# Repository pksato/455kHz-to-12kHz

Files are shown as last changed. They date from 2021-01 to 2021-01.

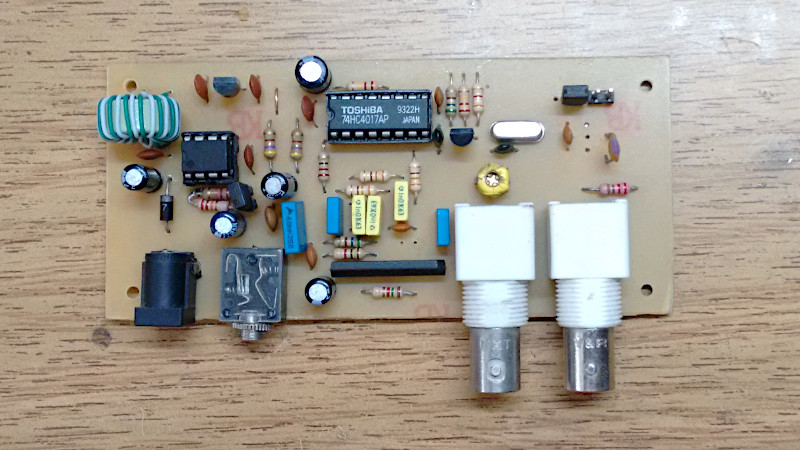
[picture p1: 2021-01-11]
if-455-to-12khz_bnc.jpg

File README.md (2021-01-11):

# IF down converter, 455kHz to 12kHz.
This converter allow a shortwave radio to decode DRM (Digital Radio Mondiale) broadcast using a SDR software.  
  
The circuit use a LA1186N or TA7358AP as mixer, and a analog television chrominance crystal as source to local oscillator.  
The crystal frequency are divide by IC301, and need to selected between 74HC4017 or 74HC4040, depending on choosen crystal frequency.  
To get 12kHz output use 4.433619MHz (PAL) crystal and 74HC4017.  
Using the 74HC4040 and 3.579545MHz (NTSC) or 3.575611MHz (PAL-M) crystal, the output frequency are centered near 8kHz.  
The input impedance of converter are great that 6k.  
Total gain is 12dB.  
  
On the radio, FI signal need to tapped after last IF stage of after 455kHz ceramic filter. Use a 47pF (or lowwer) to decouple the signal.  
  
...

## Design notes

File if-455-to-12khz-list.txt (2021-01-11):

455kHz to 12kHz converter part list.
  
Part	Value         	Description
  C101	10nF          	Ceramic Capacitor
  C102	100pF         	Ceramic Capacitor
  C103	3n3           	Ceramic Capacitor
  C104	100uFx16V       Electrolytic Capacitor
  C105	100nF         	Ceramic Capacitor
  C201	2.2uFx16V       Electrolytic Capacitor
  C202	560pF         	Ceramic Capacitor
  C203	2.2uFx16V       Electrolytic Capacitor
  C204	10uFx16V        Electrolytic Capacitor
  C205	100nF         	Ceramic Capacitor
  C301	27pF          	Ceramic Capacitor
  C302	27pF          	Ceramic Capacitor
  C303	100pF         	Ceramic Capacitor
  C304	100nF         	Ceramic Capacitor
  C305	1nF           	Ceramic Capacitor
  C306	1nF           	Ceramic Capacitor
  C307	1nF           	Ceramic Capacitor
  C308	100pF         	Ceramic Capacitor
  C401	100uFx16V       Electrolytic Capacitor
  C402	100nF         	Ceramic Capacitor
  C403	100nF         	Ceramic Capacitor
  C404	100nF         	Ceramic Capacitor
  C405	10uFx16V        Electrolytic Capacitor
 CV101	40pF          	Ceramic Trimmer
 CX101	3n3           	Only for TA7358AP - Ceramic Capacitor
  D401	1N4007        	Diode
 IC101	LA1186N       	Or TA7358AP - FM RF Front End.
 IC201	LM1458N       	Dual OpAmp
 IC301	DIL16         	74HC4017 or 74HC4040 
                        (according to the chosen crystal, see schematic)
 IC401	78L05         	Voltage regulator
  J101	1503_09       	3.5mm Jack
  J202	1503_09       	3.5mm Jack
  J401	JACK-PLUG0    	Power Jack
  L401/L402	            Common mode choke, bifilar winding on ferrite toroid
  Q301	KSP2222A      	NPN Transistor
  R101	1k5           	Resistor 1/8W
  R102	(560)         	390Ohms for TA7358AP Resistor 1/8W
  R103	1k            	Resistor 1/8W
  R201	10k           	Resistor 1/8W
  R202	4k7           	Resistor 1/8W
  R203	4k7           	Resistor 1/8W
  R301	220k          	Resistor 1/8W
  R302	560           	Resistor 1/8W
  R303	3k9           	Resistor 1/8W
  R304	220k          	Resistor 1/8W
  R305	330           	Resistor 1/8W
  R306	330           	Resistor 1/8W
  R307	330           	Resistor 1/8W
  R401	22            	Resistor 1/8W
  X301	MHz           	PAL 4.433619MHz, PAL-M 3.575611MHz or
                        NTSC 3.579545Mhz Chroma Crystal.

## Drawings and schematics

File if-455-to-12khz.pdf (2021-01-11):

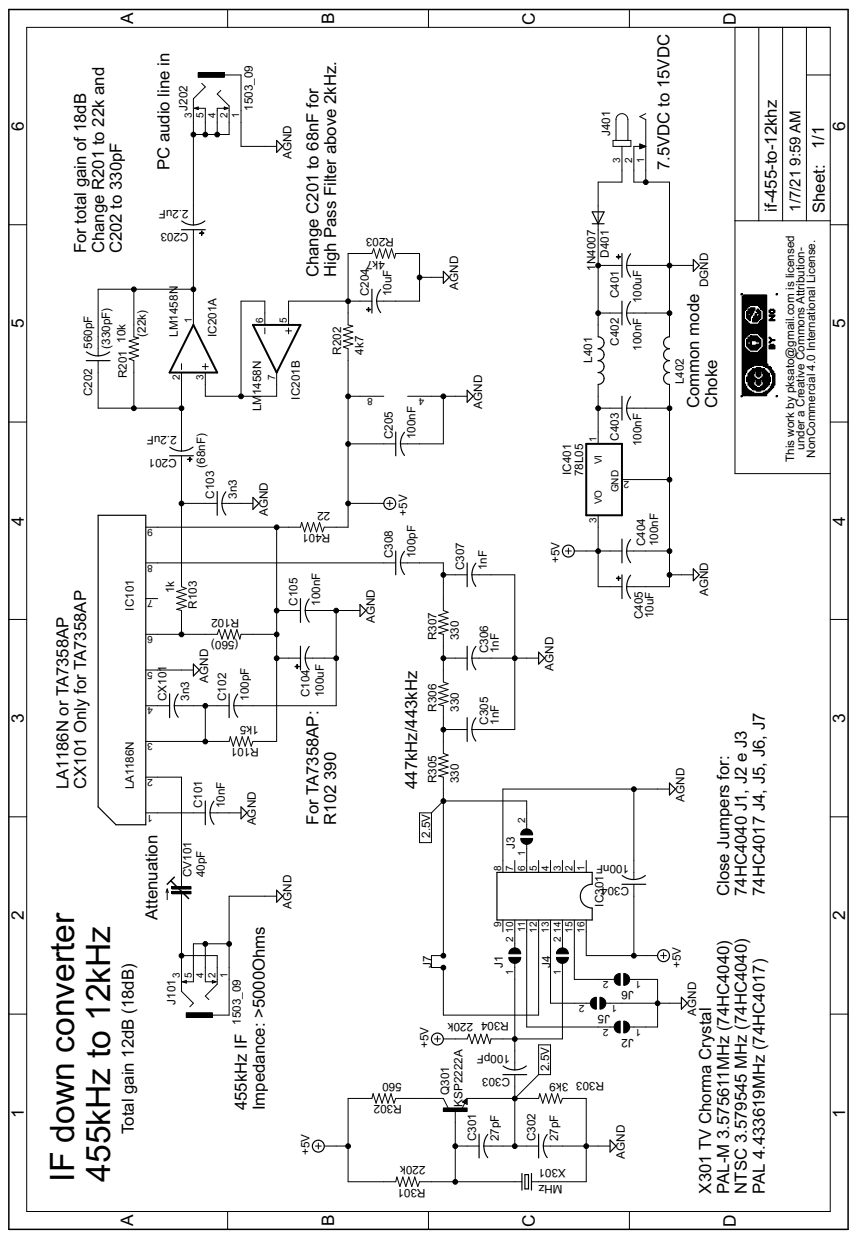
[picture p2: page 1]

PC audio line in

High Pass Filter above 2kHz.

For total gain of 18dB

This work by pksato@gmail.com is licensed under a Creative Commons Attribution-

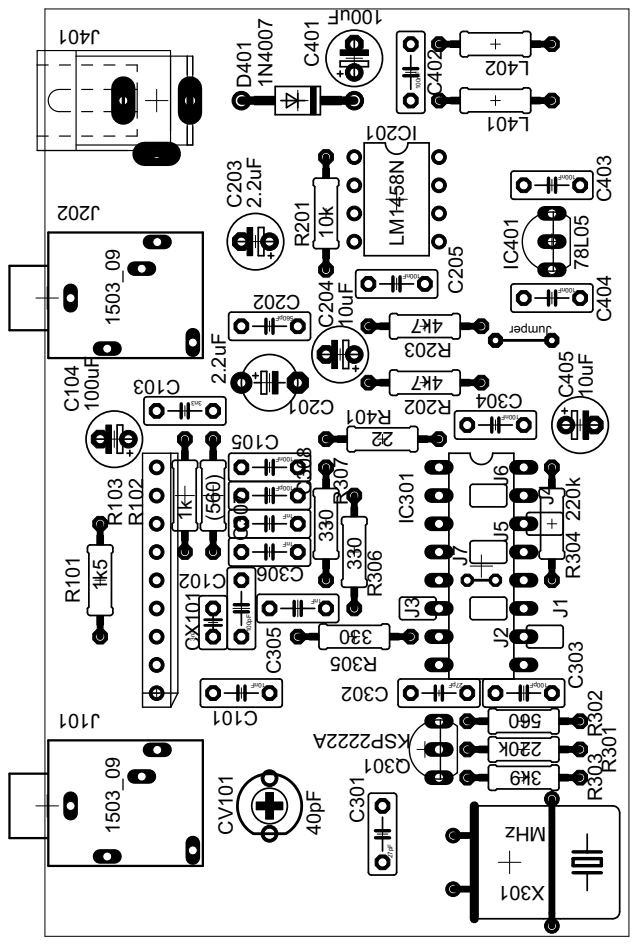
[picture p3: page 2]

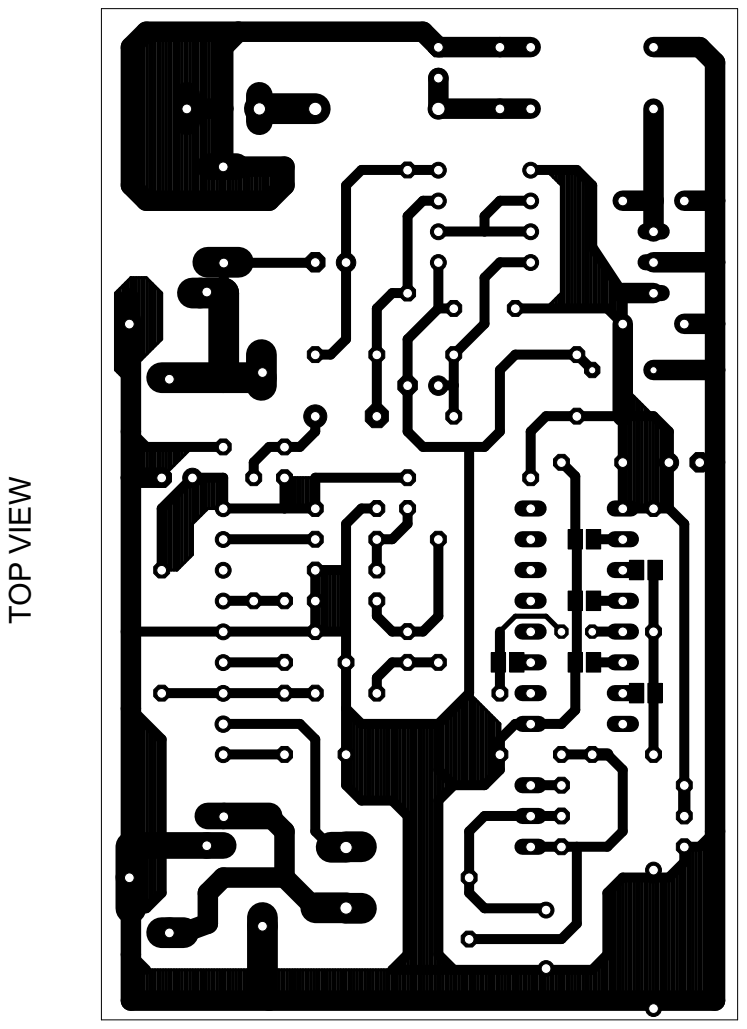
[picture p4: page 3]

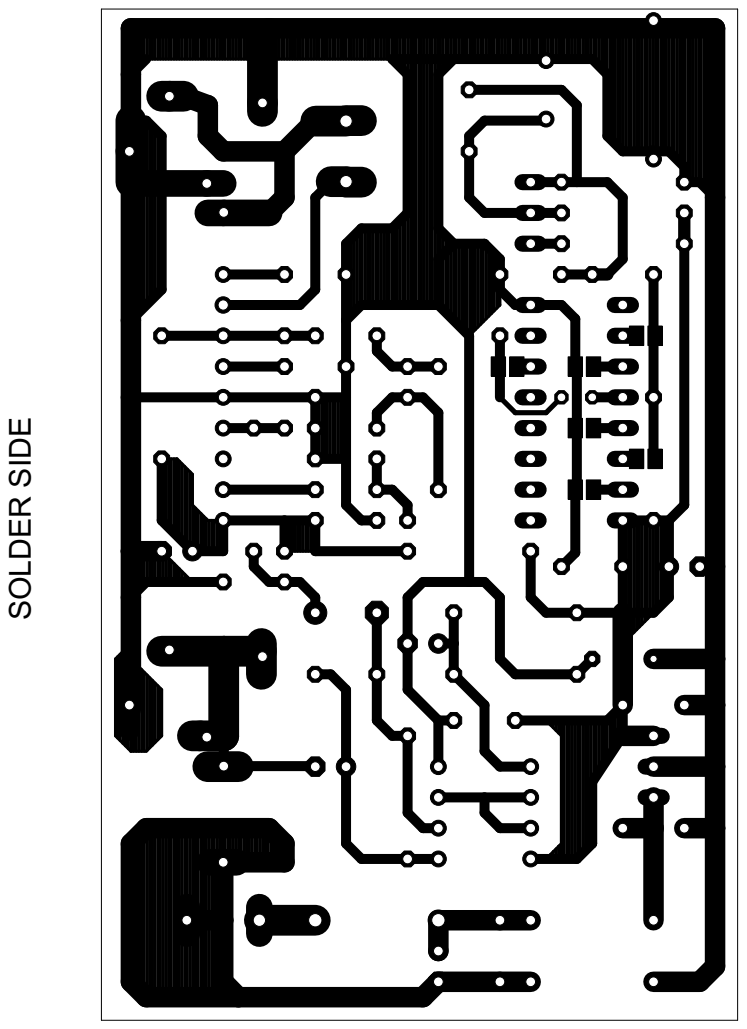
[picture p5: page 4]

455kHz to 12kHz converter part list.

Part | Value | Description
C101 | 10nF | Ceramic Capacitor
C102 | 100pF | Ceramic Capacitor
C103 | 3n3 | Ceramic Capacitor
C104 | 100uFx16V | Electrolytic Capacitor
C105 | 100nF | Ceramic Capacitor
C201 | 2.2uFx16V | Electrolytic Capacitor
C202 | 560pF | Ceramic Capacitor
C203 | 2.2uFx16V | Electrolytic Capacitor
C204 | 10uFx16V | Electrolytic Capacitor
C205 | 100nF | Ceramic Capacitor
C301 | 27pF | Ceramic Capacitor
C302 | 27pF | Ceramic Capacitor
C303 | 100pF | Ceramic Capacitor
C304 | 100nF | Ceramic Capacitor
C305 | 1nF | Ceramic Capacitor
C306 | 1nF | Ceramic Capacitor
C307 | 1nF | Ceramic Capacitor
C308 | 100pF | Ceramic Capacitor
C401 | 100uFx16V | Electrolytic Capacitor
C402 | 100nF | Ceramic Capacitor
C403 | 100nF | Ceramic Capacitor
C404 | 100nF | Ceramic Capacitor
C405 | 10uFx16V | Electrolytic Capacitor
CV101 | 40pF | Ceramic Trimmer
CX101 | 3n3 | Only for TA7358AP - Ceramic Capacitor
D401 | 1N4007 | Diode
IC101 | LA1186N | Or TA7358AP - FM RF Front End.
IC201 | LM1458N | Dual OpAmp
IC301 | DIL16 | 74HC4017 or 74HC4040
| | (according to the chosen crystal, see schematic)
IC401 | 78L05 | Voltage regulator
J101 | 1503_09 | 3.5mm Jack
J202 | 1503_09 | 3.5mm Jack
J401 | JACK-PLUG0 | Power Jack
L401/L402 | Common mode choke, bifilar winding on ferrite toroid
Q301 | KSP2222A | NPN Transistor
R101 | 1k5 | Resistor 1/8W
R102 | (560) | 390Ohms for TA7358AP Resistor 1/8W
R103 | 1k | Resistor 1/8W
R201 | 10k | Resistor 1/8W
R202 | 4k7 | Resistor 1/8W
R203 | 4k7 | Resistor 1/8W
R301 | 220k | Resistor 1/8W
R302 | 560 | Resistor 1/8W
R303 | 3k9 | Resistor 1/8W
R304 | 220k | Resistor 1/8W
R305 | 330 | Resistor 1/8W
R306 | 330 | Resistor 1/8W
R307 | 330 | Resistor 1/8W
R401 | 22 | Resistor 1/8W
X301 | MHz | PAL 4.433619MHz, PAL-M 3.575611MHz or
| | NTSC 3.579545Mhz Chroma Crystal.

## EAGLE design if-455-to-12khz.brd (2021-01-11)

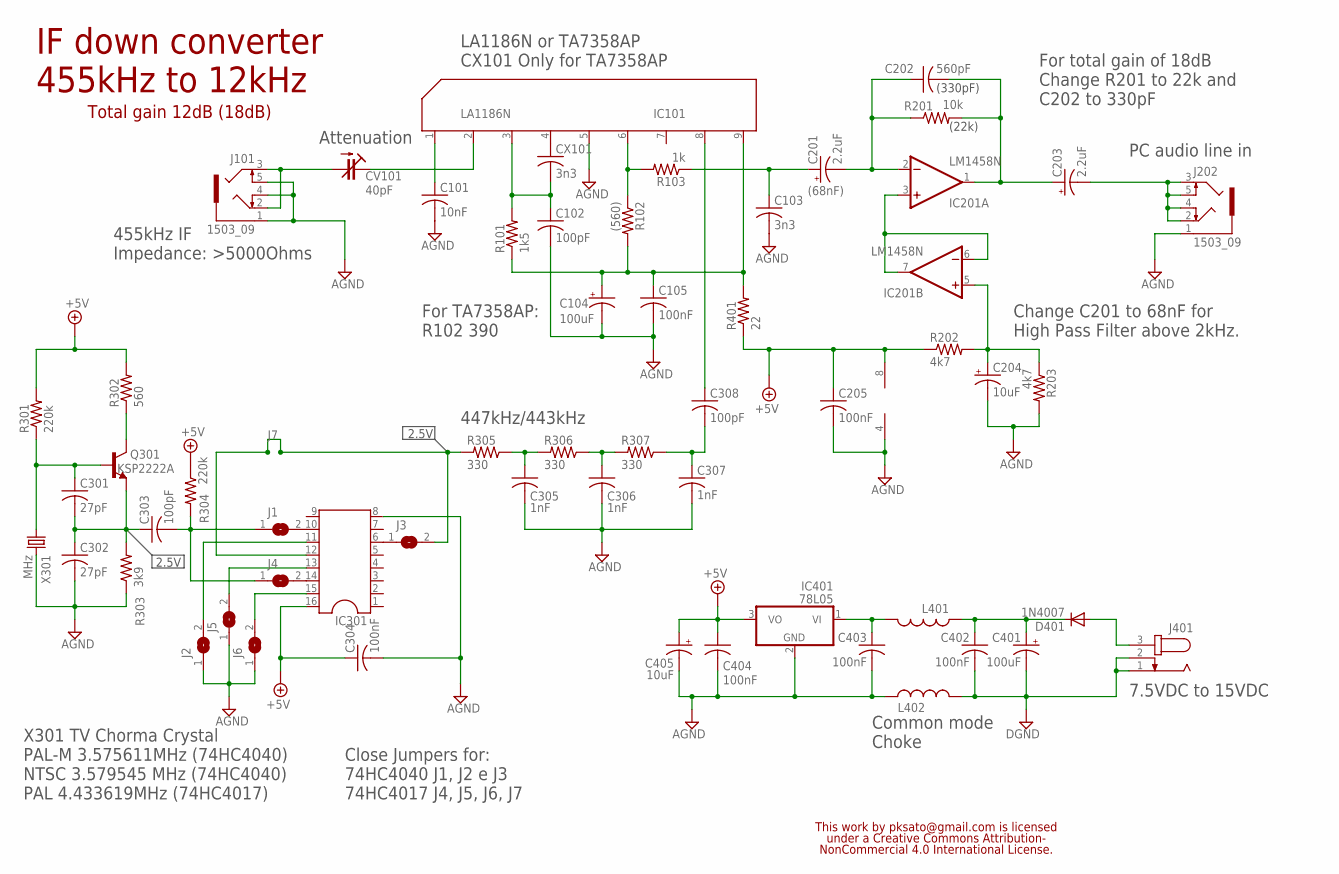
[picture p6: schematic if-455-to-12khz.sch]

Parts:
C101: 10nF; C050-025X075
C102, C303, C308: 100pF; C050-025X075
C103: 3n3; C050-025X075
C104, C401: 100uF; E2,5-5
C105, C205, C304, C402, C403, C404: 100nF; C050-025X075
C201: 2.2uF; E5-5
C202: 560pF; C050-025X075
C203: 2.2uF; E2,5-5
C204, C405: 10uF; E2,5-5
C301, C302: 27pF; C050-025X075
C305, C306, C307: 1nF; C050-025X075
CV101: 40pF; CTRIMTZ03
CX101: 3n3; C025-025X050
D401: 1N4007; DO41-10
IC101: LA1186N; SIP09
IC201: LM1458N; DIL08
IC301: DIL16
IC401: 78L05; TO92-
J1, J2, J3, J4, J5, J6: SJ
J101, J202: 1503_09
J401: JACK-PLUG0; SPC4077
L401, L402: L-US0207/10; 0207/10
Q301: KSP2222A; TO92-EBC
R101: 1k5; 0207/10
R102: (560); 0207/10
R103: 1k; 0207/10
R201: 10k; 0207/10
R202, R203: 4k7; 0207/10
R301, R304: 220k; 0207/10
R302: 560; 0207/10
R303: 3k9; 0207/10
R305, R306, R307: 330; 0207/10
R401: 22; 0207/10
X301: MHz; HC49U-LM

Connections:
+5V: C205.1, C304.1, C404.1, C405.+, IC201.8 (V+), IC301.16, IC401.3 (VO), R202.1, R301.2, R302.2, R304.1, R401.1
AGND: C101.2, C102.2, C103.2, C104.-, C105.2, C204.-, C205.2, C302.2, C304.2, C305.2, C306.2, C307.2, C403.2, C404.2, C405.-, IC101.5, IC201.4 (V-), IC301.8, IC401.2 (GND), J2.1, J5.1, J6.1, J101.1, J101.4, J101.5, J202.1, L402.2, R203.2, R303.1, X301.2
DGND: C401.-, C402.2, J401.1, J401.2, L402.1
unnamed: C301.1, Q301.B, R301.1, X301.1
unnamed: C301.2, C302.1, C303.1, Q301.E, R303.2
unnamed: CV101.2 (A), J101.2, J101.3
unnamed: C101.1, IC101.1
unnamed: IC301.12, J3.2, R305.2
unnamed: C104.+, C105.1, IC101.9, R101.1, R102.2, R401.2
unnamed: C303.2, J1.1, J4.1, R304.2
unnamed: C305.1, R305.1, R306.2
unnamed: C306.1, R306.1, R307.2
unnamed: C102.1, CX101.2, IC101.3, R101.2
unnamed: CV101.1 (E), IC101.2
unnamed: C308.1, IC101.8
unnamed: C307.1, C308.2, R307.1
unnamed: IC101.6, R102.1, R103.2
unnamed: C103.1, C201.+, R103.1
unnamed: C403.1, IC401.1 (VI), L401.1
unnamed: C202.2, C203.+, IC201.1 (OUT), R201.2
unnamed: C201.-, C202.1, IC201.2 (-IN), R201.1
unnamed: IC201.3 (+IN), IC201.6 (-IN), IC201.7 (OUT)
unnamed: C203.-, J202.2, J202.3, J202.4, J202.5
unnamed: CX101.1, IC101.4
unnamed: Q301.C, R302.1
unnamed: IC301.14, J4.2
unnamed: IC301.10, J1.2
unnamed: IC301.11, J2.2
unnamed: IC301.15, J6.2
unnamed: IC301.13, J5.2
unnamed: D401.A, J401.3
unnamed: IC301.6, J3.1
unnamed: C401.+, C402.1, D401.C, L401.2
unnamed: C204.+, IC201.5 (+IN), R202.2, R203.1

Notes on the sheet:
LA1186N or TA7358AP CX101 Only for TA7358AP
X301 TV Chorma Crystal PAL-M 3.575611MHz (74HC4040) NTSC 3.579545 MHz (74HC4040) PAL 4.433619MHz (74HC4017)
455kHz IF Impedance: >5000Ohms
PC audio line in
447kHz/443kHz
Close Jumpers for: 74HC4040 J1, J2 e J3 74HC4017 J4, J5, J6, J7
For TA7358AP: R102 390
This work by pksato@gmail.com is licensed under a Creative Commons Attribution- NonCommercial 4.0 International License.
Common mode Choke
7.5VDC to 15VDC
Attenuation
IF down converter 455kHz to 12kHz
Total gain 12dB (18dB)
(68nF)
Change C201 to 68nF for High Pass Filter above 2kHz.
(330pF)
(22k)
For total gain of 18dB Change R201 to 22k and C202 to 330pF
2.5V

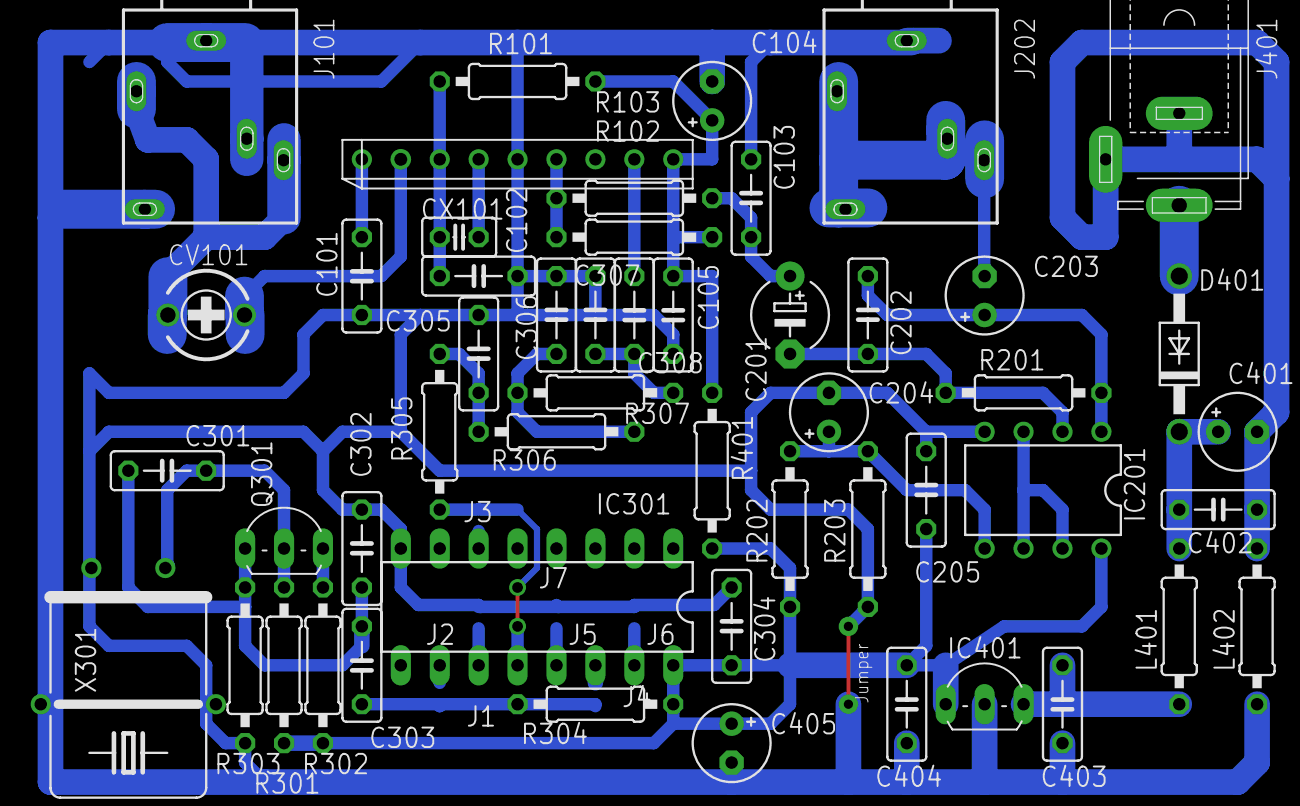
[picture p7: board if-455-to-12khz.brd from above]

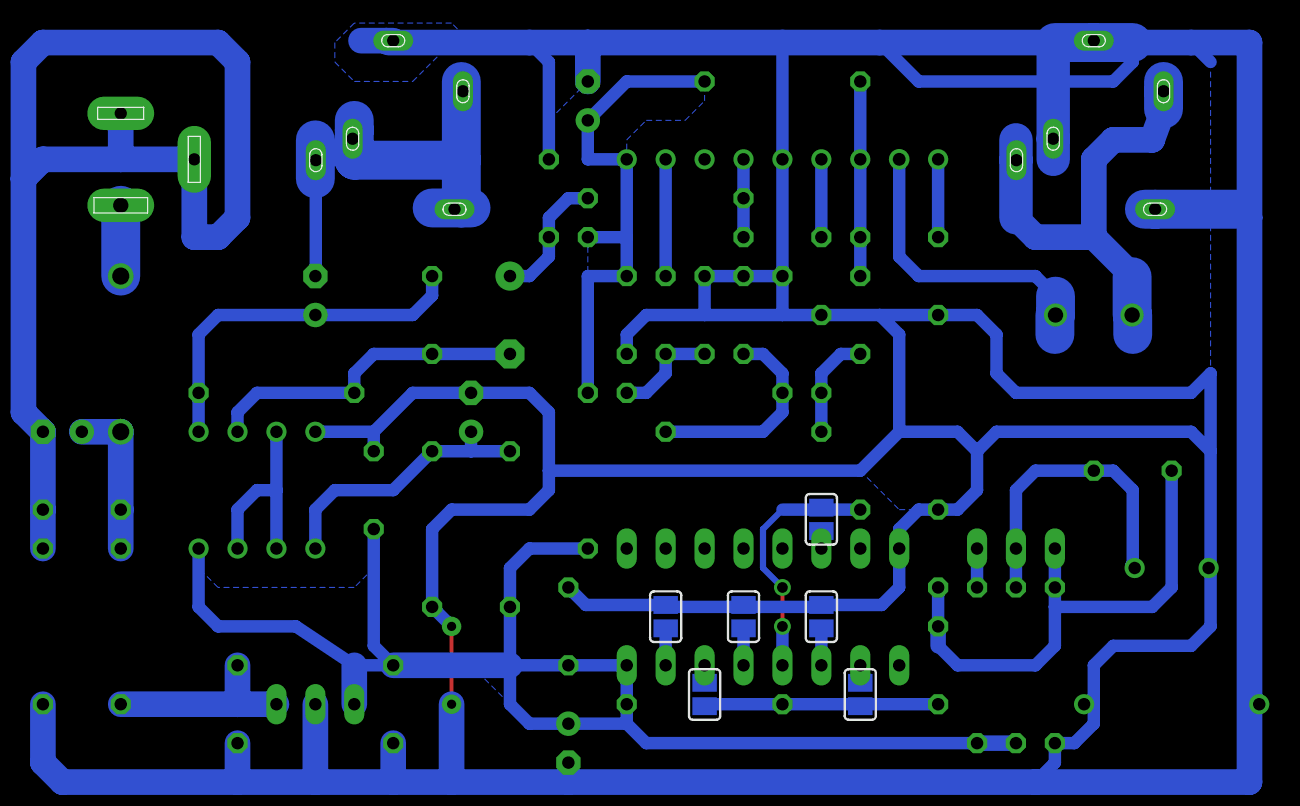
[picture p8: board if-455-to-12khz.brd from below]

Board: 2 copper layers, 57 parts (6 on the bottom side), 34 nets.

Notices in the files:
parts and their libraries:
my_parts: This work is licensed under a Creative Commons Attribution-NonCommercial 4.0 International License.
